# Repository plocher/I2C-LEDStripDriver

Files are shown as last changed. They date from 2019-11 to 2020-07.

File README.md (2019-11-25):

# I2C-LEDStripDriver
## License: CERN Open Hardware Licence v1.2

I2C LED Strip Driver based on a PCA9685 

The PCA9685 is an I2C-bus controlled 16-channel LED controller optimized for Red/Green/Blue/Amber (RGBA) color backlighting applications.
Each LED output has its own 12-bit resolution (4096 steps) fixed frequency individual PWM controller

This design drives 2x RGB LED strips and 2x "white" strips - one set for backdrop lighting (dawn and dusk sunsets...) and the other for overhead (sunlight) valence illumination.

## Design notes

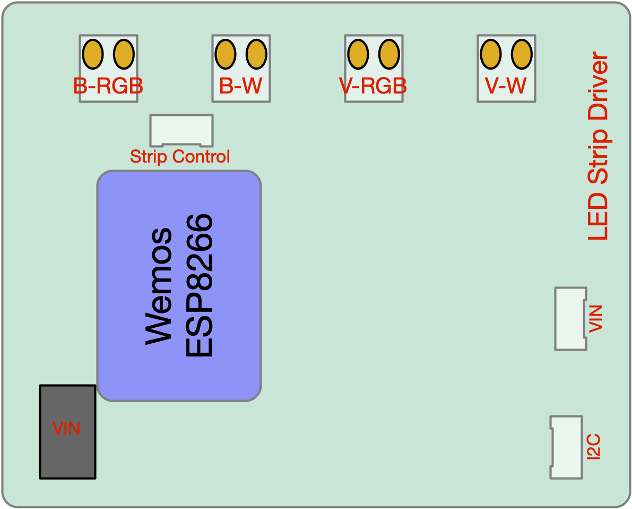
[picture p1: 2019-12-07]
I2C-LEDStripDriver-Graphic.png

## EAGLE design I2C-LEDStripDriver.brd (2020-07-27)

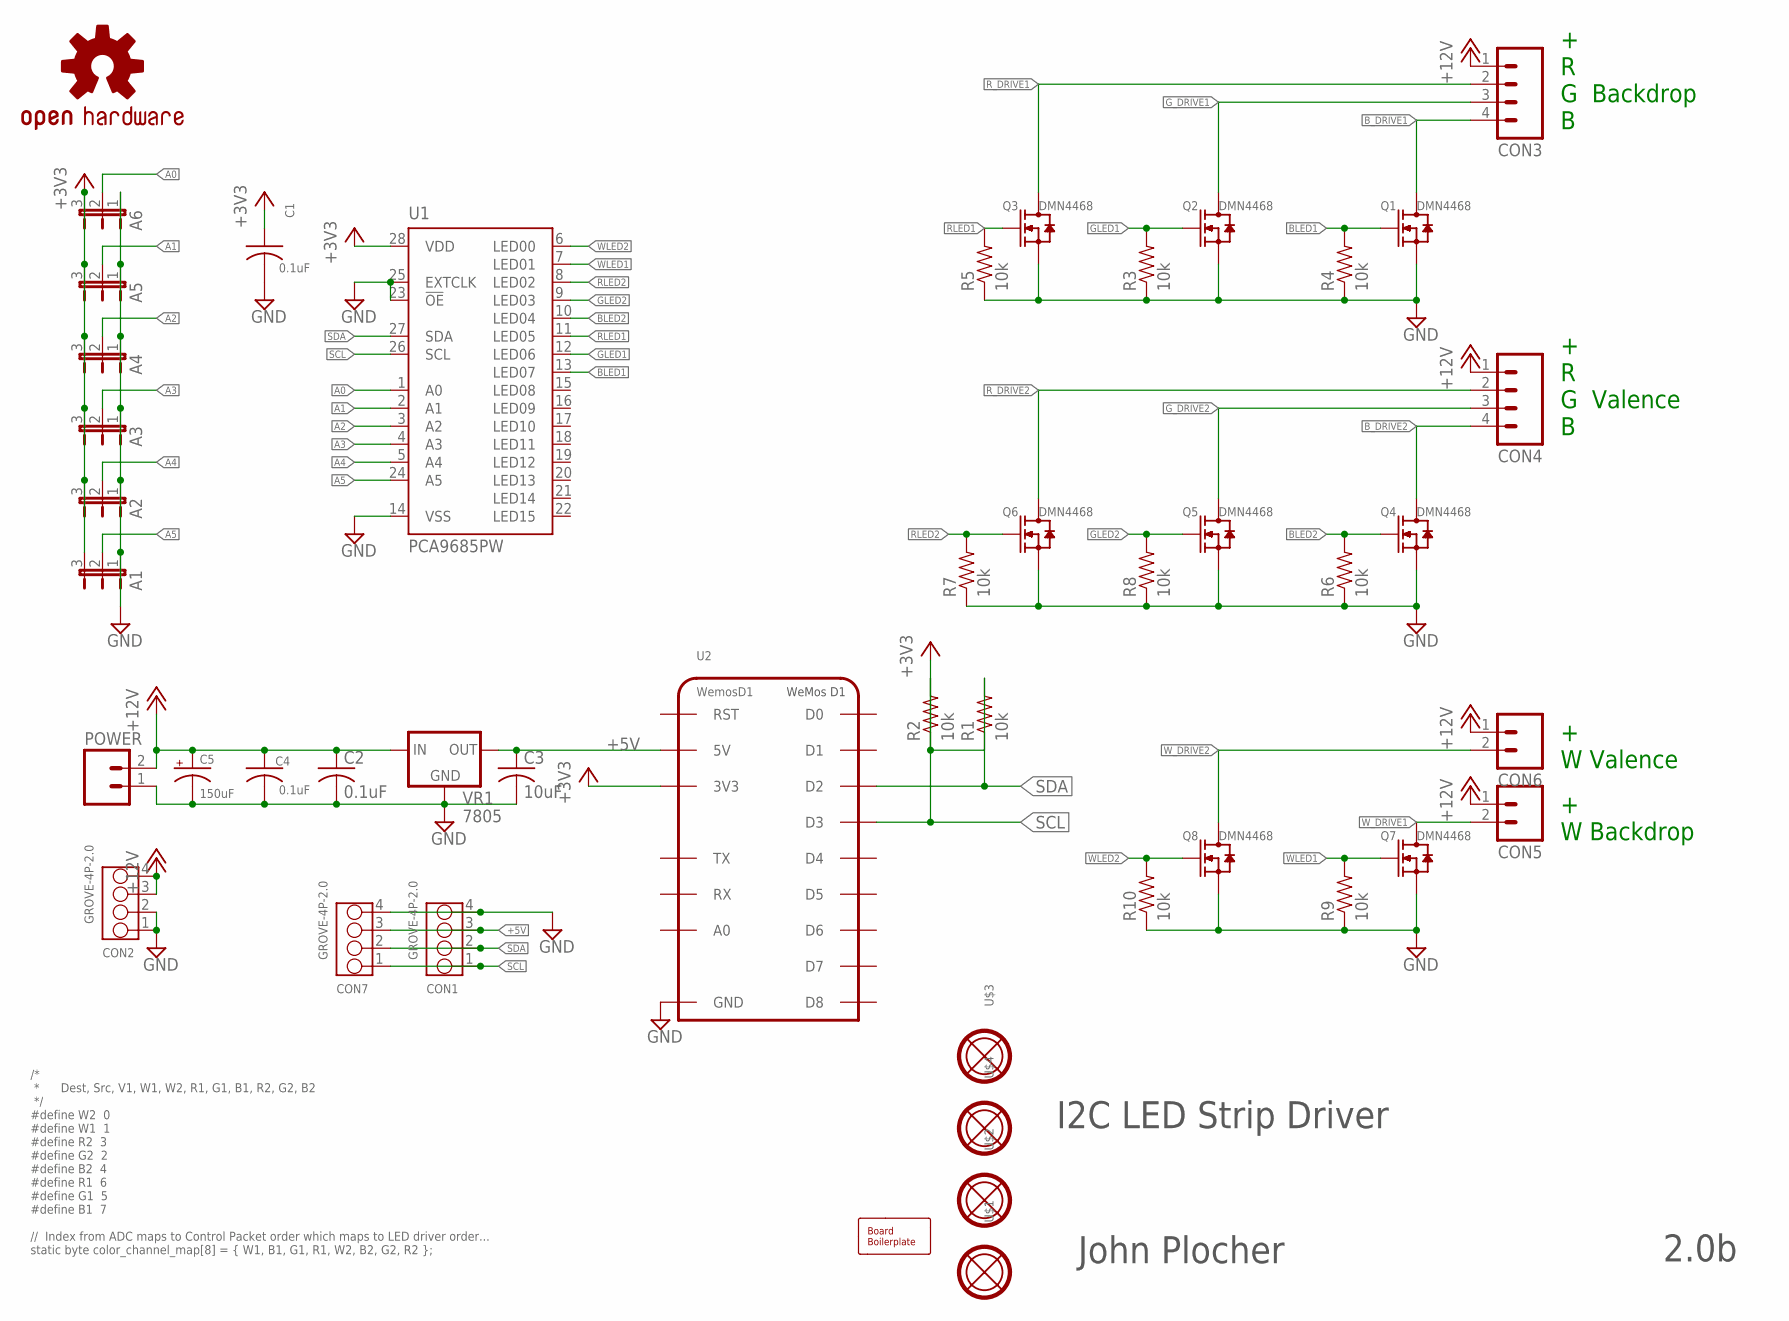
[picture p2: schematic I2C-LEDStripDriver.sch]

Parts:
A1, A2, A3, A4, A5, A6: JUMPER-3PTH-LOCK; 1X03
BOARD1: BOARD80X100-TEMPLATE; BOARD-10X8-TEMPLATE
C1, C4: 0.1uF; 0603-CAP
C2: 0.1uF; 0805-CAP
C3: 10uF; 0805-CAP
C5: 150uF; 0810-CAP
CON1, CON2, CON7: GROVE-4P-2.0; 4P-2.0
CON3, CON4: CONNECTOR-M045.08; MSTBA4
CON5, CON6: CONNECTOR-M02MSTBA2; MSTBA2
OSHW1: OSHW-LOGOL; OSHW-LOGO-L
POWER: CONNECTOR-M02MSTBA2; MSTBA2
Q1, Q2, Q3, Q4, Q5, Q6, Q7, Q8: DMN4468; SO08
R1, R2, R3, R4, R5, R6, R7, R8, R9, R10: 10k; 0603-RES
U1: PCA9685PW; TSSOP28
U2: WemosD1; WEMOS-D1
U$1, U$2, U$3, U$4: MOUNTINGHOLE
VR1: 7805; TO-252

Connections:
+3V3: A1.3, A2.3, A3.3, A4.3, A5.3, A6.3, C1.1, R1.1, R2.1, U1.28 (VDD), U2.3V3
+5V: C3.1, CON1.3, CON7.3, U2.5V, VR1.3 (OUT)
+12V: C2.1, C4.1, C5.+, CON2.3, CON2.4, CON3.1, CON4.1, CON5.1 (A), CON6.1 (A), POWER.2 (B), VR1.1 (IN)
A0: A6.2, U1.1 (A0)
A1: A5.2, U1.2 (A1)
A2: A4.2, U1.3 (A2)
A3: A3.2, U1.4 (A3)
A4: A2.2, U1.5 (A4)
A5: A1.2, U1.24 (A5)
BLED1: Q1.4 (G), R4.2, U1.13 (LED07)
BLED2: Q4.4 (G), R6.2, U1.10 (LED04)
B_DRIVE1: CON3.4, Q1.5 (D), Q1.6 (D), Q1.7 (D), Q1.8 (D)
B_DRIVE2: CON4.4, Q4.5 (D), Q4.6 (D), Q4.7 (D), Q4.8 (D)
GLED1: Q2.4 (G), R3.2, U1.12 (LED06)
GLED2: Q5.4 (G), R8.2, U1.9 (LED03)
GND: A1.1, A2.1, A3.1, A4.1, A5.1, A6.1, C1.2, C2.2, C3.2, C4.2, C5.-, CON1.4, CON2.1, CON2.2, CON7.4, POWER.1 (A), Q1.1 (S), Q1.2 (S), Q1.3 (S), Q2.1 (S), Q2.2 (S), Q2.3 (S), Q3.1 (S), Q3.2 (S), Q3.3 (S), Q4.1 (S), Q4.2 (S), Q4.3 (S), Q5.1 (S), Q5.2 (S), Q5.3 (S), Q6.1 (S), Q6.2 (S), Q6.3 (S), Q7.1 (S), Q7.2 (S), Q7.3 (S), Q8.1 (S), Q8.2 (S), Q8.3 (S), R3.1, R4.1, R5.1, R6.1, R7.1, R8.1, R9.1, R10.1, U1.14 (VSS), U1.23 (!OE), U1.25 (EXTCLK), U2.GND, VR1.2 (GND)
G_DRIVE1: CON3.3, Q2.5 (D), Q2.6 (D), Q2.7 (D), Q2.8 (D)
G_DRIVE2: CON4.3, Q5.5 (D), Q5.6 (D), Q5.7 (D), Q5.8 (D)
RLED1: Q3.4 (G), R5.2, U1.11 (LED05)
RLED2: Q6.4 (G), R7.2, U1.8 (LED02)
R_DRIVE1: CON3.2, Q3.5 (D), Q3.6 (D), Q3.7 (D), Q3.8 (D)
R_DRIVE2: CON4.2, Q6.5 (D), Q6.6 (D), Q6.7 (D), Q6.8 (D)
SCL: CON1.1, CON7.1, R2.2, U1.26 (SCL), U2.D3
SDA: CON1.2, CON7.2, R1.2, U1.27 (SDA), U2.D2
WLED1: Q7.4 (G), R9.2, U1.7 (LED01)
WLED2: Q8.4 (G), R10.2, U1.6 (LED00)
W_DRIVE1: CON5.2 (B), Q7.5 (D), Q7.6 (D), Q7.7 (D), Q7.8 (D)
W_DRIVE2: CON6.2 (B), Q8.5 (D), Q8.6 (D), Q8.7 (D), Q8.8 (D)

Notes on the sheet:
I2C LED Strip Driver
John Plocher
2.0b
+ R G Backdrop B
+ R G Valence B
+ W Valence
+ W Backdrop
/* * Dest, Src, V1, W1, W2, R1, G1, B1, R2, G2, B2 */ #define W2 0 #define W1 1 #define R2 3 #define G2 2 #define B2 4 #define R1 6 #define G1 5 #define B1 7 // Index from ADC maps to Control Packet order which maps to LED driver order... static byte color_channel_map[8] = { W1, B1, G1, R1, W2, B2,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

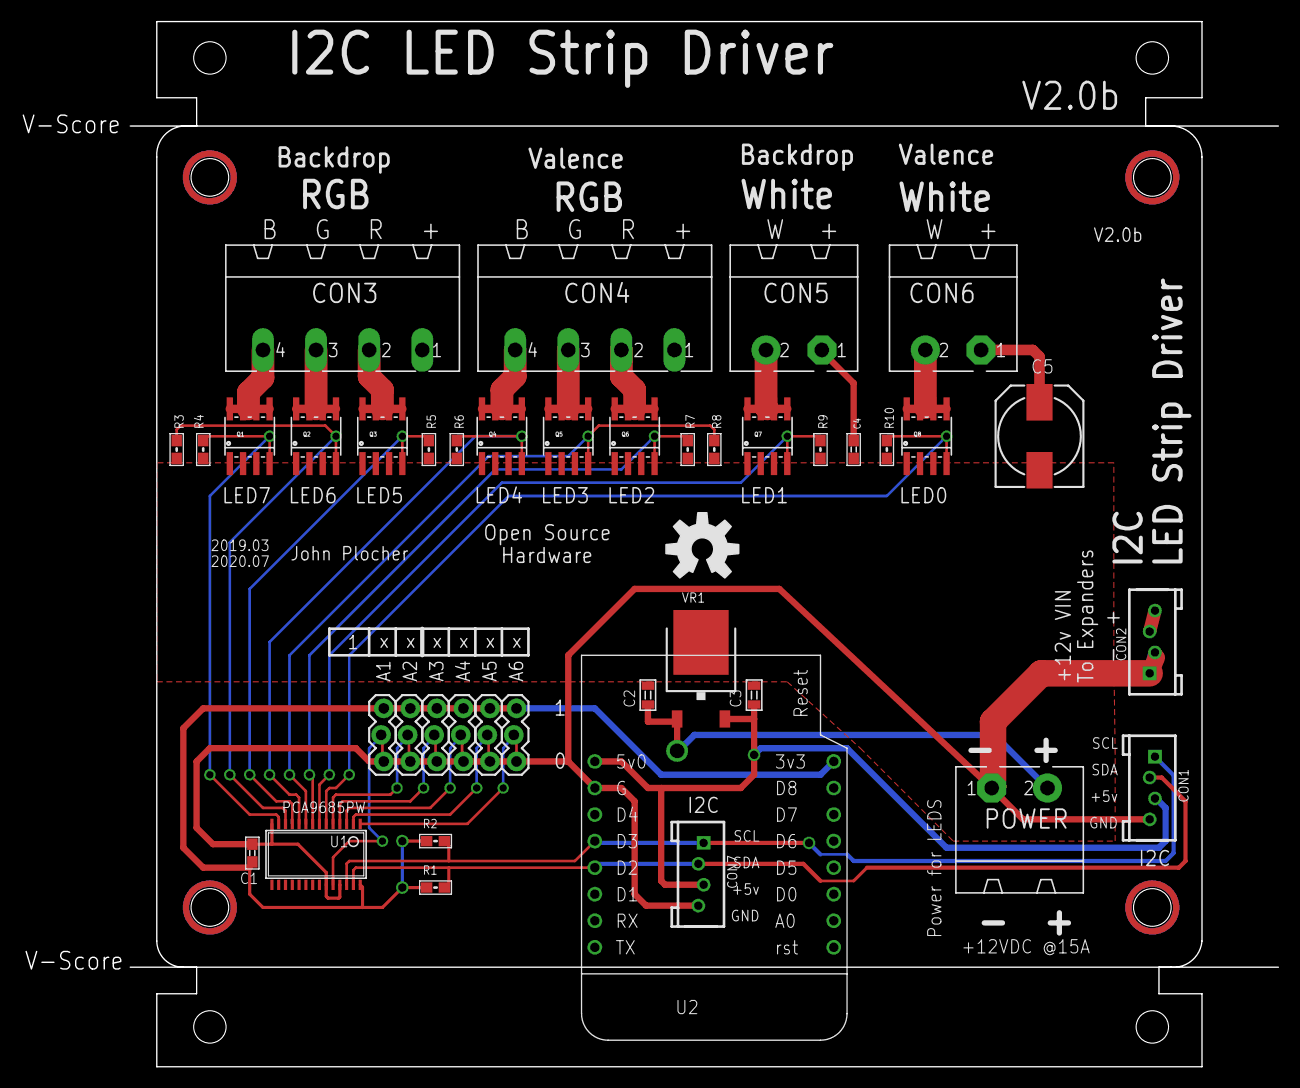
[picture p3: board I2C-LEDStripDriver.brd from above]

Board: 2 copper layers, 109.9 x 100.0 mm, 46 parts (0 on the bottom side), 28 nets.
